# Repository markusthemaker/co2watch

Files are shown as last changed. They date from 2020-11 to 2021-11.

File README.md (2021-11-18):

<meta name="google-site-verification" content="mVb4j9CEitCwDcsNqLN-e2j8hI3UwMoKpGTOJ4NhaoY" />

# CO2 Wall Clock 
## Arduino / ESP powered CO2 Monitor for Schools, Offices, and Private Buildings
### Proper ventilation not only ensures well-being, but significantly reduces risk of SARS-CoV-2 infection
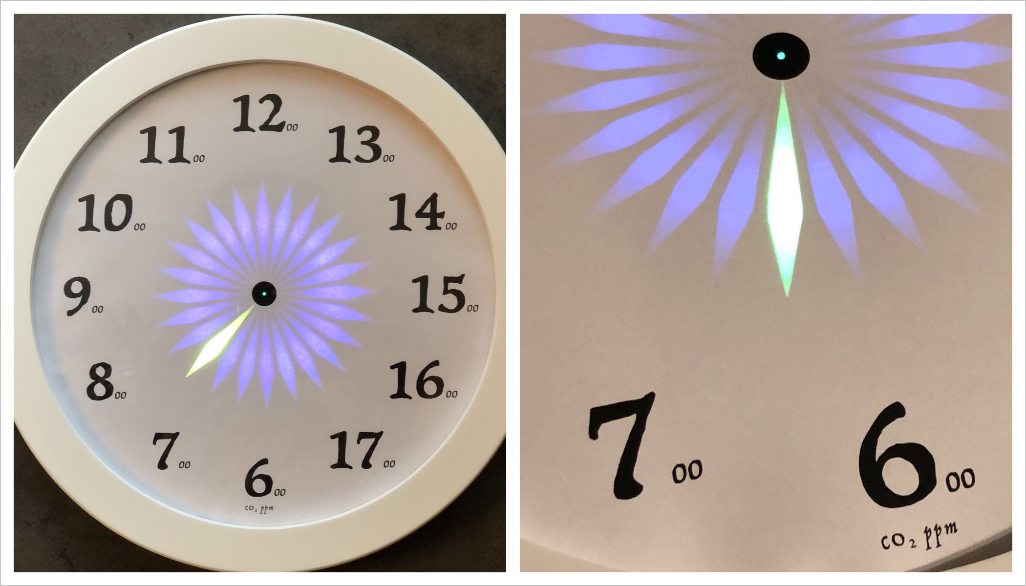
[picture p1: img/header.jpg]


## Background
“Aerosols are a possible transmission path of the novel coronavirus. Aerosols spread quickly throughout the entire room, especially in closed indoor spaces. Regular ventilation by shock and cross ventilation or via ventilation systems can significantly reduce the risk of infection with SARS-CoV-2.” [[Source]](https://www.umweltbundesamt.de/en/press/pressinformation/proper-airing-reduces-risk-of-sars-cov-2-infection)

Every person is emitting CO2 as well as aerosols while breathing. CO2 concentration correlates with the aerosol and thus virus concentration. CO2 is also a good indicator for the efficiency of the ventilation. 
<p align="center">
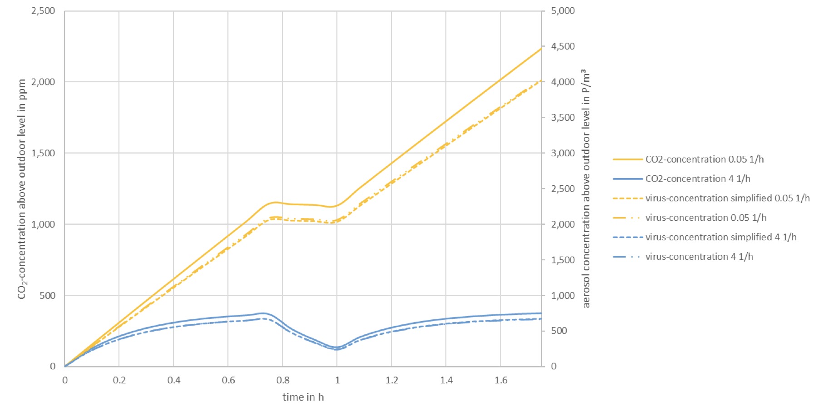
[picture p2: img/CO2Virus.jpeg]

  
Figue: Modelling Co2 concentration (solid) and virus load (dotted) in a classroom with (blue) and without ventilation (yellow). <a href="https://depositonce.tu-berlin.de/bitstream/11303/11478.3/9/hartmann_kriegel_2020_en_v3.pdf">[Source: http://dx.doi.org/10.14279/depositonce-10362.3]</a>
</p>

## Why a CO2 Monitor? 
We can all assess and gauge air quality when entering a room (from the outside). However, humans have no means to objectively judge air quality after a short time, given our senses adapt quickly to a situation [Source](https://en.wikipedia.org/wiki/Neural_adaptation). Most people do not even notice the incremental worsening of air quality and see no good reason to vent a room often.

Air quality cannot be measured directly, but CO2 concentration is the most important proxy. Outside air has typically CO2 concentration of around 410 ppm. The concentration of exhaled CO2 is in the excess of approx. 38’000 ppm. Indoor CO2 level considered acceptable is 1’000 ppm, a level that is reached in a room quickly [Source](https://en.wikipedia.org/wiki/Indoor_air_quality)

A CO2 monitor helps to keep a room well-vented and is thought a mandatory utility during the pandemic.

## Design Considerations 
Most CO2 monitors use a (small) digital display that requires your attention to read the CO2 concentration. In this design the concept of a wall clock was chosen for direct visual feedback and intuitive reading. It is well suited for schools, offices and private buildings.

Indoors, concentrations below 600 ppm are of short nature, and exceeding 1’000 ppm suggests inadequate ventilation. Therefore the range from 600-1750 ppm is more than sufficient for indoor operation. 

Moreover, the ppm concentration is color coded and shall relate to the importance to air the room; green-amber-red-purple. 

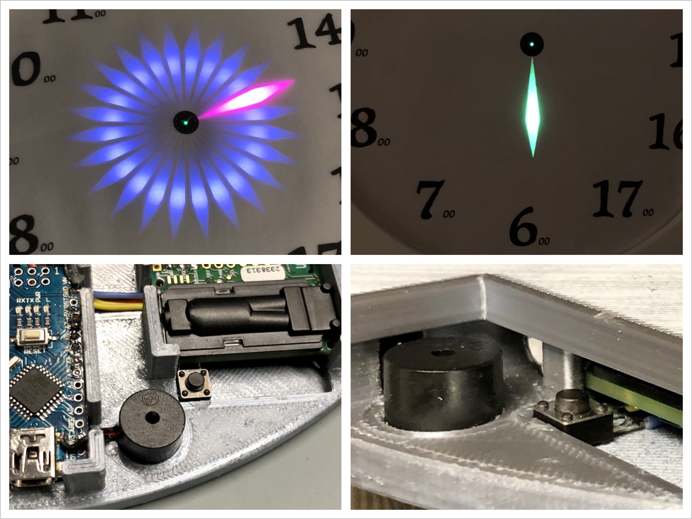
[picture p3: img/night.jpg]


In the center of the watch face a red/green status LED indicates if a warning buzzer is active or not. If active, the buzzer sends a 50 ms signal every 3 minutes when hitting 1000 ppm, and with increasing concentration warns more often; at 1'750 ppm the buzzer is activated every 10 seconds. 

The buzzer can be turned off/on with a small button that is located nearby the buzzer. Recommen-dation is to keep the buzzer active at all times. 

## Features
- **Accurate:** NDIR CO2 sensor with +/-30ppm +5ppm (calibrated)
- **Visual:** Display CO2 concentration on a watch face. Range: <=6 to >=17.5 (x100ppm) 
- **Intuitive:** RGB LED relates to CO2 ppm concentration (green-amber-red-purple) 
- **24/7 Operation:** Light sensitive resistor (LDR) adapts brightness of LEDs 
- **Audible:** Integrated buzzer warns when reaching 1000 ppm 
- **Do Not Disturb:** Buzzer can be switched on/off with status LED on watch face

## Parts List (~100€)
- Picture Frame (~10€): https://www.amazon.de/dp/B07D4MQ9ZR
- Arduino Nano v3.0 Microcontroller Board (clone) (~6€): https://www.amazon.de/dp/B078SBBST6/
- High-precision Sensor: Sensirion SCD 30 (~50€): https://shop.watterott.com/Sensirion-SCD30-CO2-Kohlendioxid-Sensor
- 24 NeoPixel LED ring WS2812 (Adafruit) 5.3 cm (~11€): https://www.amazon.de/dp/B07QLMPV6S
- 3 mm dual color red/green 3 pin LED (Common Cathode LED) (~1€)
- Resistors: 1x 330Ω, 1x470Ω, 1x10kΩ (<1€)
- Capacitor: 470-1000µF/6.3V (<1€)
- Light Sensitive Resistor: Light: 20-30 KΩ. Darkness: 1 MΩ (~1€)
- Push Button Switch 6x6mm (<1€)
- Buzzer (<1€)
- Micro USB power supply (~5€)
- PLS or PETG 3D Printed watch face and backdrop (~5€)

## Schematics & Design Considerations
- Button needs to be connected to an Arduino pin supporting interrupts (D2 or D3).
- Sensirion SCD 30 can be read-out via PWM, Modbus, or via an I2C bus (used here). [Datasheet](https://www.sensirion.com/fileadmin/user_upload/customers/sensirion/Dokumente/9.5_CO2/Sensirion_CO2_Sensors_SCD30_Datasheet.pdf)
- Data input of Adafruit Neo Pixel LED ring shall be protected with a 470Ω resistor, and DC connection buffered with a 470-1000 µF capacitor. 
- Buzzer is driven directly by low power Arduino output. For more power, a MOSFET driver circuit could be integrated.  
- Schmatic and wiring diagram below, incl. a pinout of the used Arduino Nano.

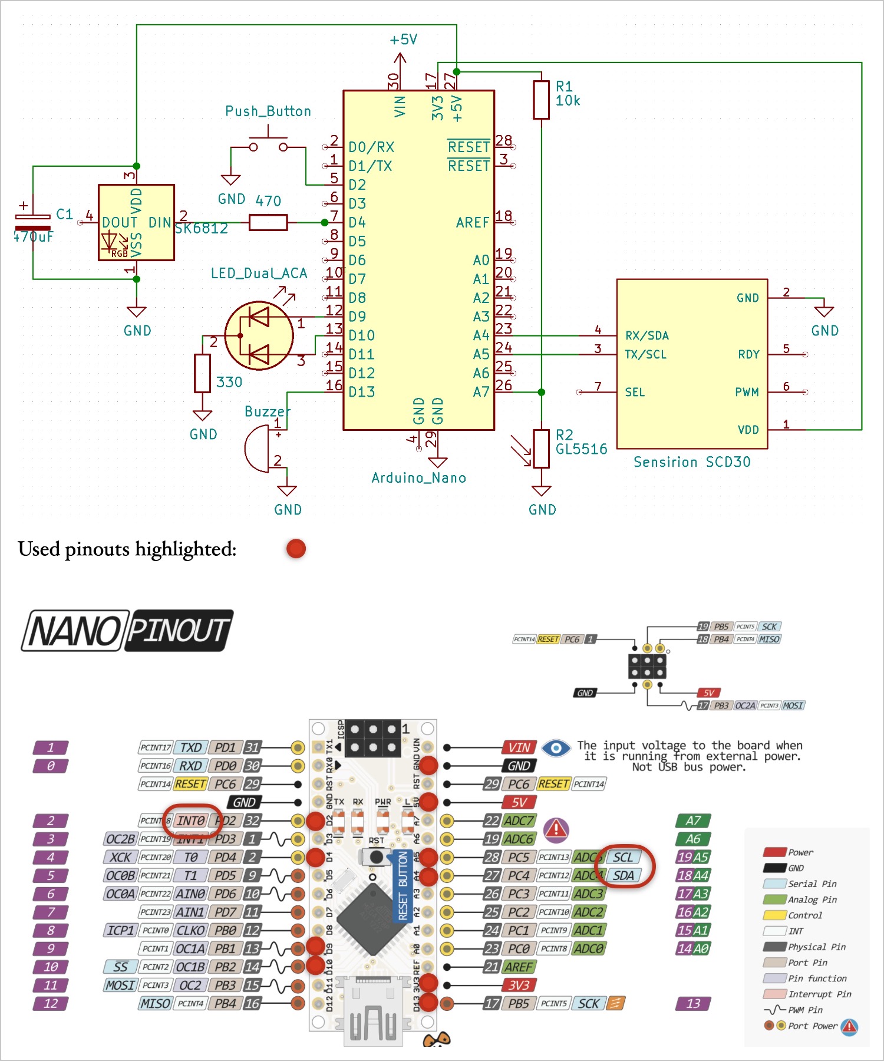
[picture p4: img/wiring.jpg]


## 3D CAD Design & 3D Print
- Designed for LEDs to function like an “analogue wach”, hosting all components, while fitting into the picture frame. CO2 sensor mount with open air vents. Design principle: “quick & dirty”, but functional ;)
- Print with silver-like PLA. Do not use white, otherwise LED chamber separation is not perfect due to some translucency. 
- Link to my 3D CAD design: [Onshape](https://cad.onshape.com/documents/eb4fe6fd7e007a0c0a804747/w/9b61381e8207a3fee56fc157/e/aed4f8af9d3ca59d0a31d5e0) Branches: Arduino & ESP - choose the right one for your purpose.
- Link to STLs: [3D_STL_Files](3D_STL_Files/) for Arduino and ESP8266 (the latter has not been printed/tested)

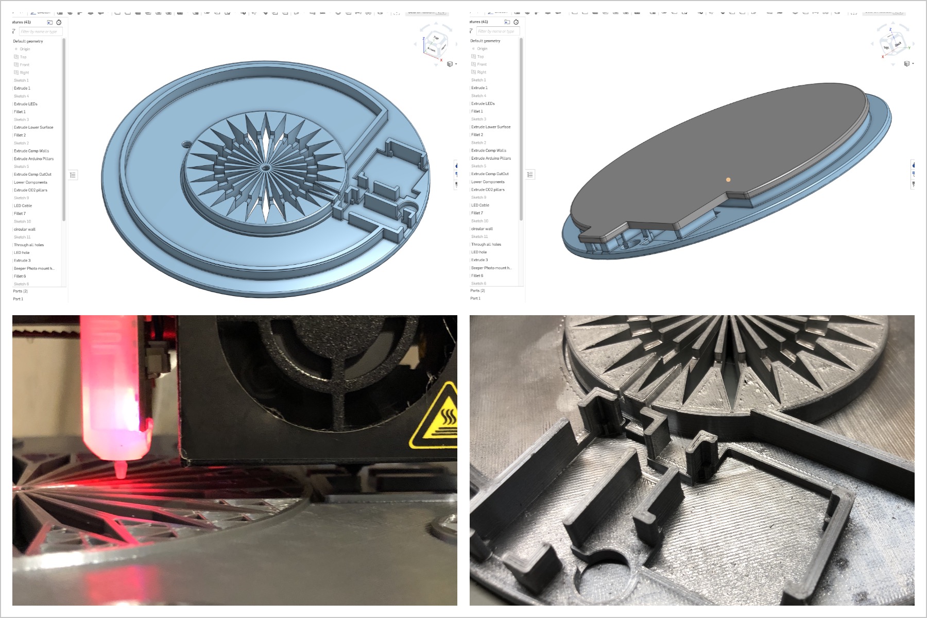
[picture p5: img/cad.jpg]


## Watch Face Design
- Link to pdf and Apple Keynote file: [2D Design Files](2D_Watchface/)
- Best printed on semi-transparent paper; cut-out and place in front of 3D print

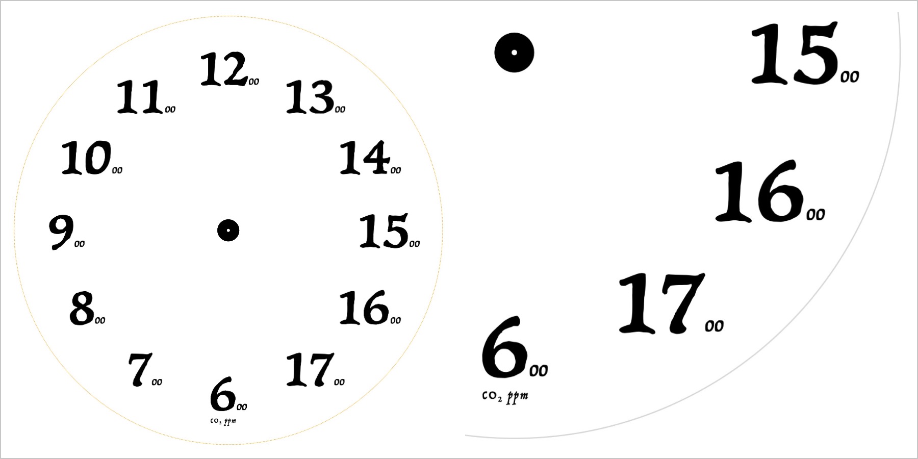
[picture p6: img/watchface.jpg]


## Component Test
It is strongly advised to wire up the components step-by-step, and testing each added functionaly with the debug code snippets in the ino file. After each functional entity is tested, the full assembly is fully operational on a breadboard. At this point the transfer into the 3D printed housing can begin :)  

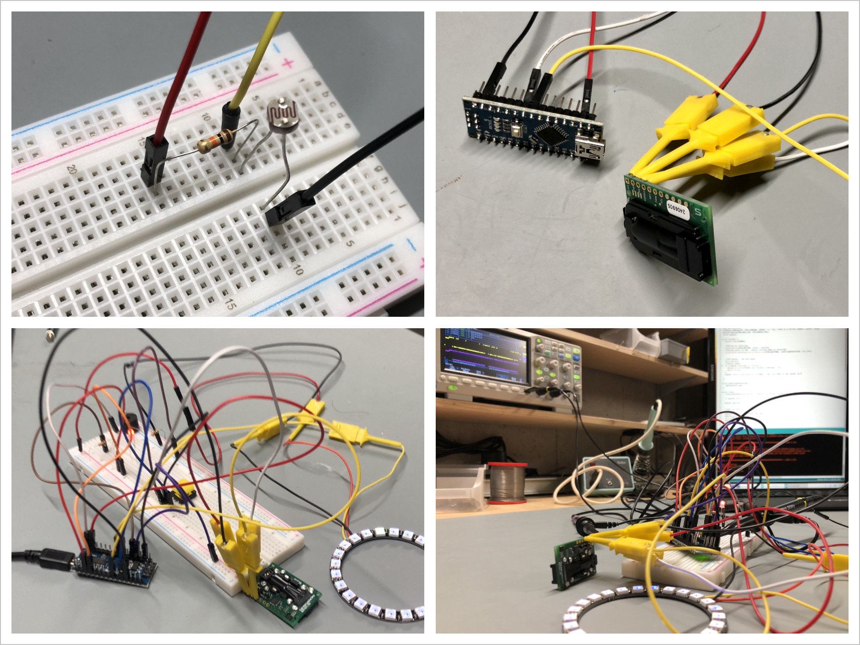
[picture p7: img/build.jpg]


## Assembly

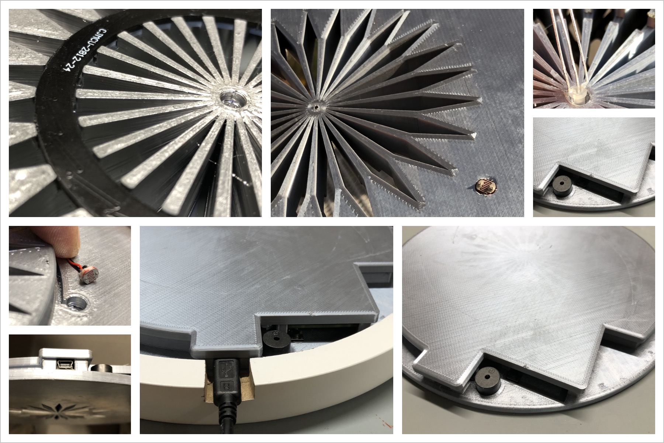
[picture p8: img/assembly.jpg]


## Operation

#### Power
The Arduino boad is placed in such a way that the Micro USB connection can be used to power the CO2 Watch 

#### 24/7 Operation
Ambient brightness is measured and LEDs adapt to the given lighting situation, so the CO2 Watch can do its job 24/7.

#### Where to place? 
Install away from windows and  doors and do not place within the proximity of people (>1 m).

# License Information

## Concept, 3D Print, 2D Watch Face 

Project files such as 3D Print and 2D Design and Concept files are released under [Creative Commons Share-alike 4.0 International](http://creativecommons.org/licenses/by-sa/4.0/)

Note: Below is a human-readable summary of and not a substitute for the [license](http://creativecommons.org/licenses/by-sa/4.0/legalcode)

#### You are free to:

- Share — copy and redistribute the material in any medium or format
- Adapt — remix, transform, and build upon the material for any purpose, even commercially.

The licensor cannot revoke these freedoms as long as you follow the license terms.

#### Under the following terms:

- Attribution — You must give appropriate credit, provide a link to the license, and indicate if changes were made. You may do so in any reasonable manner, but not in any way that suggests the licensor endorses you or your use.
- ShareAlike — If you remix, transform, or build upon the material, you must distribute your contributions under the same license as the original.
- No additional restrictions — You may not apply legal terms or technological measures that legally restrict others from doing anything the license permits.

## Software Code 

**Software is released under the MIT License (http://opensource.org/licenses/MIT).**

The MIT License (MIT)

Copyright (c) 2020 Markus Brosch

Permission is hereby granted, free of charge, to any person obtaining a copy
of this software and associated documentation files (the "Software"), to deal
in the Software without restriction, including without limitation the rights
to use, copy, modify, merge, publish, distribute, sublicense, and/or sell
copies of the Software, and to permit persons to whom the Software is
furnished to do so, subject to the following conditions:

The above copyright notice and this permission notice shall be included in all copies or substantial portions of the Software.

THE SOFTWARE IS PROVIDED "AS IS", WITHOUT WARRANTY OF ANY KIND, EXPRESS OR
IMPLIED, INCLUDING BUT NOT LIMITED TO THE WARRANTIES OF MERCHANTABILITY,
FITNESS FOR A PARTICULAR PURPOSE AND NONINFRINGEMENT. IN NO EVENT SHALL THE
AUTHORS OR COPYRIGHT HOLDERS BE LIABLE FOR ANY CLAIM, DAMAGES OR OTHER
LIABILITY, WHETHER IN AN ACTION OF CONTRACT, TORT OR OTHERWISE, ARISING FROM,
OUT OF OR IN CONNECTION WITH THE SOFTWARE OR THE USE OR OTHER DEALINGS IN THE
SOFTWARE.

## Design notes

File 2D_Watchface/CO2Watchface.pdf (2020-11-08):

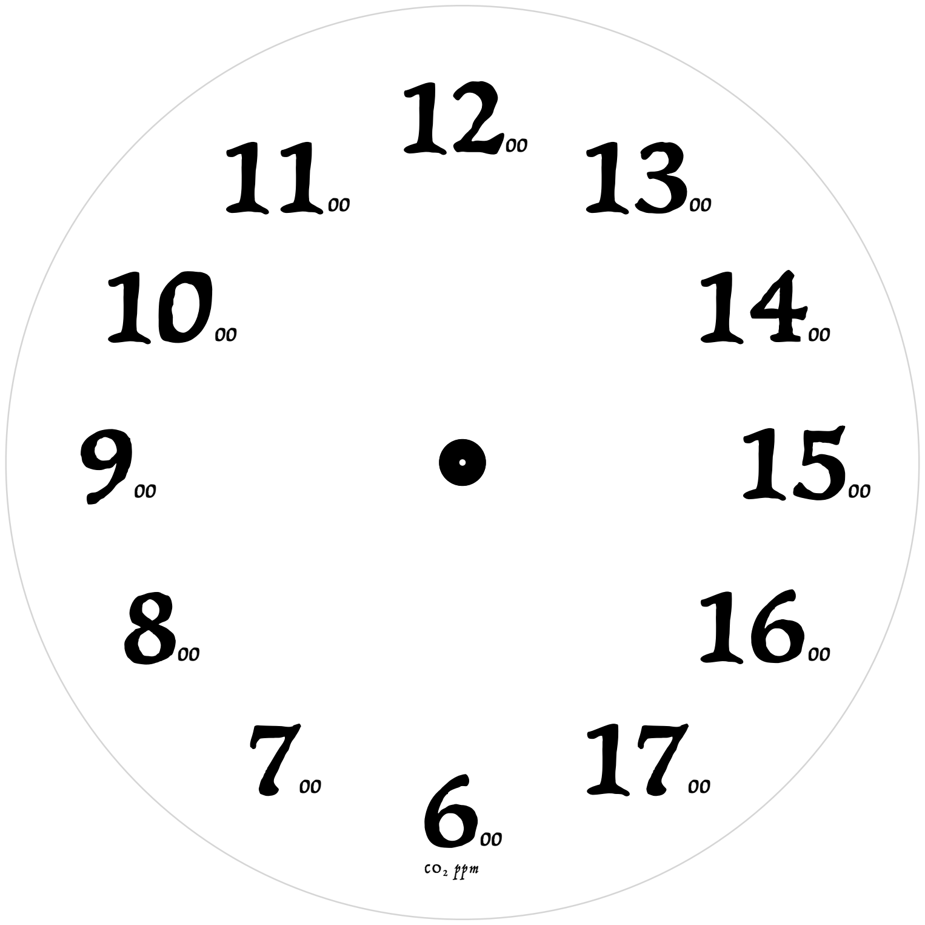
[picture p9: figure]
CO2 ppm

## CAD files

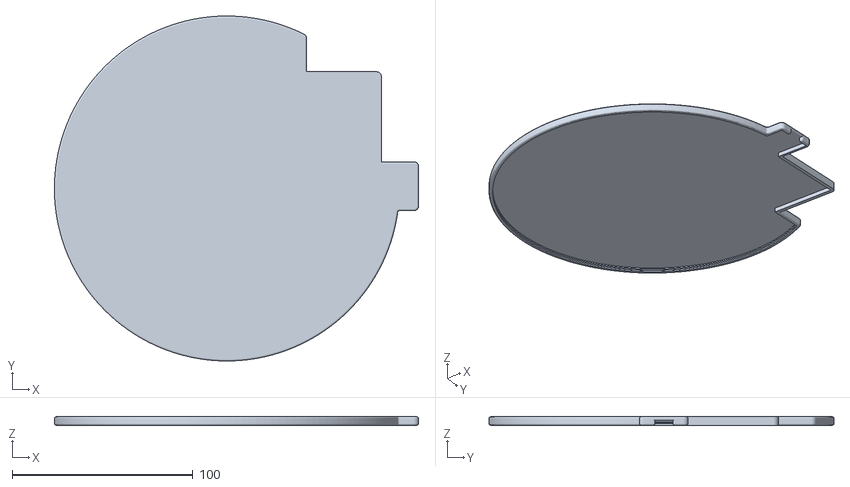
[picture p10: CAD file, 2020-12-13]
3D_STL_Files/Cover Arduino Nano 45x18.stl
201.4 x 190.8 x 4.71

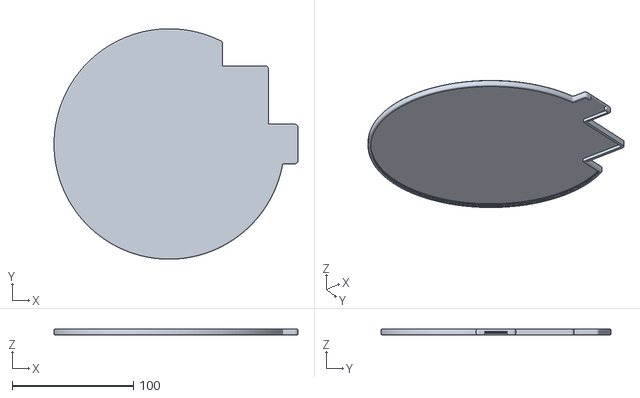
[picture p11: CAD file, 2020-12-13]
3D_STL_Files/Cover ESP8266 48x26.stl
201.6 x 190.4 x 4.71

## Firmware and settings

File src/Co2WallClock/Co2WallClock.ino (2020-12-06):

#include <SparkFun_SCD30_Arduino_Library.h>
#include <Wire.h>

#include "Buzzer.h"
#include "Timer.h"
#include "LDR.h"
#include "LEDRing.h"
#include "DuoLED.h"

//PINS
const byte PIN_BUZZER = 13;
const byte PIN_LDR = A7;
const byte PIN_LEDRING = 4;
const byte PIN_BUTTON = 2;  //Use a pin that works for interrupts
const byte PIN_RED_LED = 10;
const byte PIN_GREEN_LED = 9;

//CO2 concentration is affected by altitude
//Altitude compensation for CO2 measurement - update for your setting
const word altitude = 250;
//Force calibration based on a reliable and known reference; only use if better than factory default
const word refCO2Value = 0; //0:No calibration; 400-2000: use trusted reference value

//Setting a flag when inerrupt is detected is an effective way to debounce a button
volatile bool buttonInterrupt = false;

//Buzzer is active if true
bool buzzerOn = true;

//Keep track of last CO2 readout
//Not every loop cylce updates CO2 - sensor delivery new data only every 2s
word co2 = 0;

Timer timer;
SCD30 sensor;
LDR ldr(PIN_LDR);
Buzzer buzzer(PIN_BUZZER);
DuoLED duoLed(PIN_RED_LED, PIN_GREEN_LED);
LEDRing ledRing(24, PIN_LEDRING, 65536 * 2 / 3); //Hue is a 16 bit number; value = blue

//Arduino specific - initializes and sets the initial values
void setup() {
  Serial.begin(9600);

  //Show LED0 for 1s
  ledRing.setBrightness(DayPeriod::DAY);
  ledRing.setLed(0);
  delay(1000);

  //Button as interrupt
  digitalWrite(PIN_BUTTON, HIGH); //pullup
  //Button pulls to GND - detect falling edge as interrupt
  attachInterrupt(digitalPinToInterrupt(PIN_BUTTON), interruptDetected, LOW);

  //CO2 sensor - I2C bus begin
  Wire.begin();
  //Sensor begin
  if (!sensor.begin(Wire, false)) {
    Serial.println("SCD30 init failed. Freezing...");
    while (true);
  }

  //Relevant when used at alitude
  sensor.setAltitudeCompensation(altitude); //Set altitude of the sensor in m
  
  //Force Calibration based on a known reference value; only use if better than factory default
  if(refCO2Value >= 400) {
    delay(120000); // 2 min CO2 sensor warm-up
    sensor.setForcedRecalibrationFactor(refCO2Value);
    Serial.println("Calibration completed; disable calibration with refCO2Value=0 and re-flash Arduino");
    while (true);
  }
}

//Used by attachInterrupt() to track status
void interruptDetected() {
  Serial.println("button interrupt");
  buttonInterrupt = true;
}

void loop() {

  //Due, Zero and MKR boards have 12-bit ADC capabilities. Set to 10-bits to work with LDR class
  //analogReadResolution(10); //default to 10 bit resolution

  //Get ambient light set LEDs to corresponding brightness (day/evening/night)
  DayPeriod dp = ldr.getState();
  ledRing.setBrightness(dp);
  duoLed.setBrightness(dp);

  //Change status if button was pressed and update status buzzer LED
  if (buttonInterrupt) {
    buzzerOn = !buzzerOn; //change status if button pressed
    delay(100); //debounce button for at least 50-100ms, otherwise it might trigger several times
    buttonInterrupt = false; //reset interrupt
    buzzer.buzz();
    Serial.print("Buzzer: "); Serial.println(buzzerOn);
  }
  //Update LED status; outside so respective LED active even without any interrupts
  (buzzerOn == true) ? duoLed.green() : duoLed.red();

  //get co2 sensor data, range ristrict it, active corresponding LED
  if (sensor.dataAvailable()) {
    co2 = sensor.getCO2();
    Serial.print("CO2(ppm):"); Serial.println(co2);

    //limit co2 to available range on watch face
    if (co2 > 1750) co2 = 1750;
    if (co2 < 600) co2 = 600;

    //Map co2 onto 24 LED range
    byte activeLed = map(co2, 600, 1750, 0, 23);

    //Update led brightness
    ledRing.setLed(activeLed);
  }

  //Set buzzer timer and set number of beeps
  if (buzzerOn) {
    byte numberBeeps = 0;
    if (co2 < 1000) {
      //If CO2 concentration falls below alarm value, we reset the timer
      timer.stopTimer();
    } else if (co2 < 1250) {
      timer.startTimer(60000); //warn every 60 seconds
      numberBeeps = 1;
    } else if (co2 < 1500) {
      timer.startTimer(30000); //warn every 30 seconds
      numberBeeps = 2;
    } else {
      timer.startTimer(15000); //earn every 15 seconds
      numberBeeps = 3;
    }

    //Activate buzzer and reset timer
    if (timer.isTimerDone()) {
      buzzer.buzz(numberBeeps);
      timer.stopTimer(); //start counting from scratch
    }
  }

  delay(1000);
}

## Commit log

2020-12-06 Add files via upload
    Added: optional forced re-calibration
2020-12-13 Add files via upload
    ESP8266 Cover/Housing untested; uploaded upon request. Arduino Nano minor tweaks - better fit of cover.
    [Cover Arduino Nano 45x18.stl, Cover ESP8266 48x26.stl]
2020-12-13 Update README.md
    Added Housing for ESP8266; untested.
2020-12-13 Update README.md
    3D printing support for ESP NodeMCU
